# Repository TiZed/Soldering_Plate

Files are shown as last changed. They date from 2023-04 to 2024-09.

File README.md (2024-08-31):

## Soldering Plate Device

This repository holds the mechanical, circuit design and firmware for a soldering plate device, built around cheap heating plates that can be bought online.

The enclosure, pictured below, is designed to be 3D printed. Some of the STLs are available in the repository.

There are two circuits, one for supplying 5V from mains to the control circuits. The second is a control circuit, for mounting an encoder for user input. Control is done using a STM32F103 board known as the "Blue Pill". 

<h3 align="center">
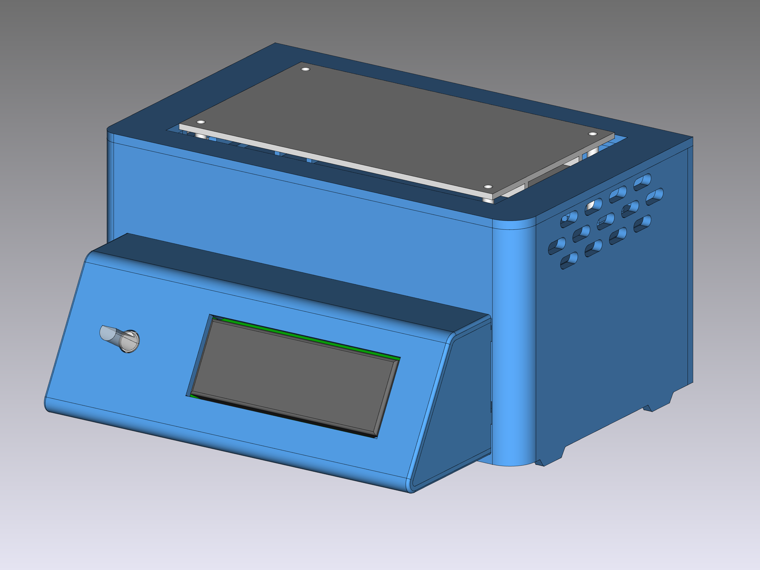
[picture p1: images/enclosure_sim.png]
Enclosure render
  
</h3>
Enclosure Render

---
<br />This work is licensed under a <a rel="license" href="http://creativecommons.org/licenses/by-nc-sa/4.0/">Creative Commons Attribution-NonCommercial-ShareAlike 4.0 International License</a>.

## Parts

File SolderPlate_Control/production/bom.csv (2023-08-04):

Designator | Footprint | Quantity | Value | LCSC Part #
C1, C2 | 0603 | 2 | 10nF
J1 | PinHeader_2x04_P2.54mm_Vertical | 1 | Encoder
Q1, Q4 | SOT-23 | 2 | Si2301CDS
R1, R4, R5, R6, R7 | 0603 | 5 | 10K
R10, R9 | 0603 | 2 | 470
R13, R14 | 0603 | 2 | 1K
R2 | 0603 | 1 | 120
R3 | 0603 | 1 | 68
U1 | RotaryEncoder_Bourns_Vertical_PEL12D-2xxxX-Sxxxx | 1 | PEL12D

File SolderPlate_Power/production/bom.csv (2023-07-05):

Designator | Footprint | Quantity | Value | LCSC Part #
C1 | C_Rect_L13.0mm_W6.0mm_P10.00mm_FKS3_FKP3_MKS4 | 1 | 100nF
C2 | CP_Elec_6.3x7.7 | 1 | 220uF
C3 | 0603 | 1 | 100nF
FL2 | L_CommonMode_PROD_PDUUAT98_L17mm_W12mm_Px7mm_Py8mm | 1 | 10mH
J1 | TestPoint_Bridge_Pitch5.08mm_Drill1.3mm | 1 | N
J2 | JST_XH_B2B-XH-A_1x02_P2.50mm_Vertical | 1 | Fan
J3 | TestPoint_Bridge_Pitch5.08mm_Drill1.3mm | 1 | L
J4 | JST_XH_B2B-XH-A_1x02_P2.50mm_Vertical | 1 | SSR
J5 | PinHeader_1x04_P2.54mm_Vertical | 1 | LCD
J7 | PinHeader_2x03_P2.54mm_Vertical | 1 | uCont
PS1 | Converter_ACDC_HiLink_HLK-PMxx | 1 | HLK-PM01
Q1, Q2, Q3 | SOT-23 | 3 | BSS138
R1 | 0603 | 1 | 68
R2, R4, R6 | 0603 | 3 | 470
R3, R5, R7 | 0603 | 3 | 10K
RV1 | RV_Disc_D12mm_W6.7mm_P7.5mm | 1 | 10D561K

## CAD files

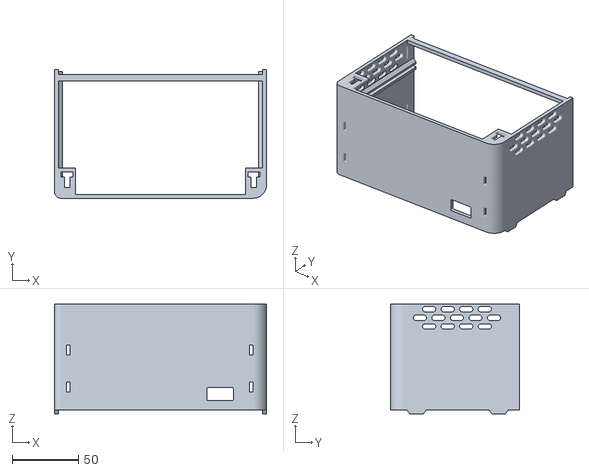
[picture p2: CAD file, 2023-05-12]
Soldering_Plate-MainCover.stl
160.0 x 97.0 x 83.0

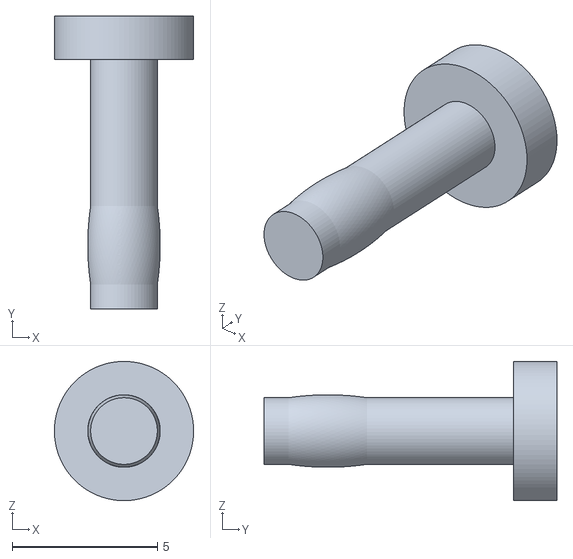
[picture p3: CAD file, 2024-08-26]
Soldering_Plate-LCD_Hold_Pin.stl
4.80 x 10.1 x 4.80

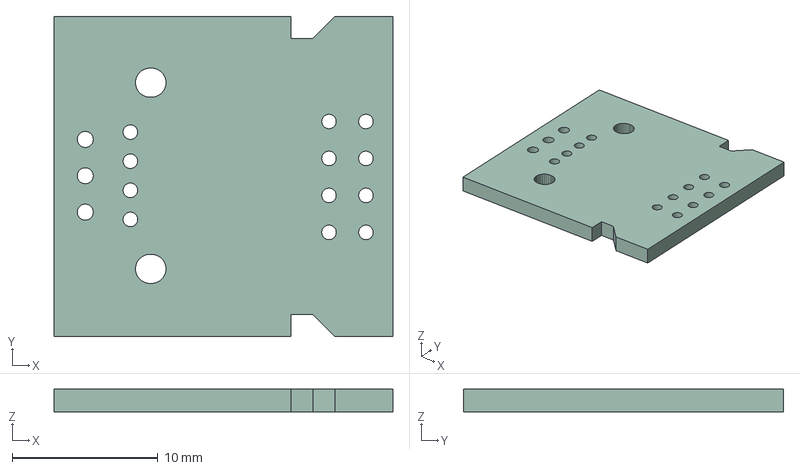
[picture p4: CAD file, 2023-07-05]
SolderPlate_Control/SolderPlate_Control.step
23.3 x 22.0 x 1.58 mm

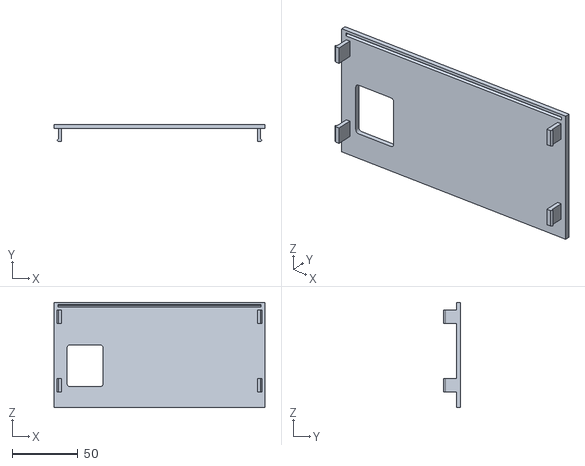
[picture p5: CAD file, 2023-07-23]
Soldering_Plate-BackCover.stl
160.0 x 12.8 x 80.0

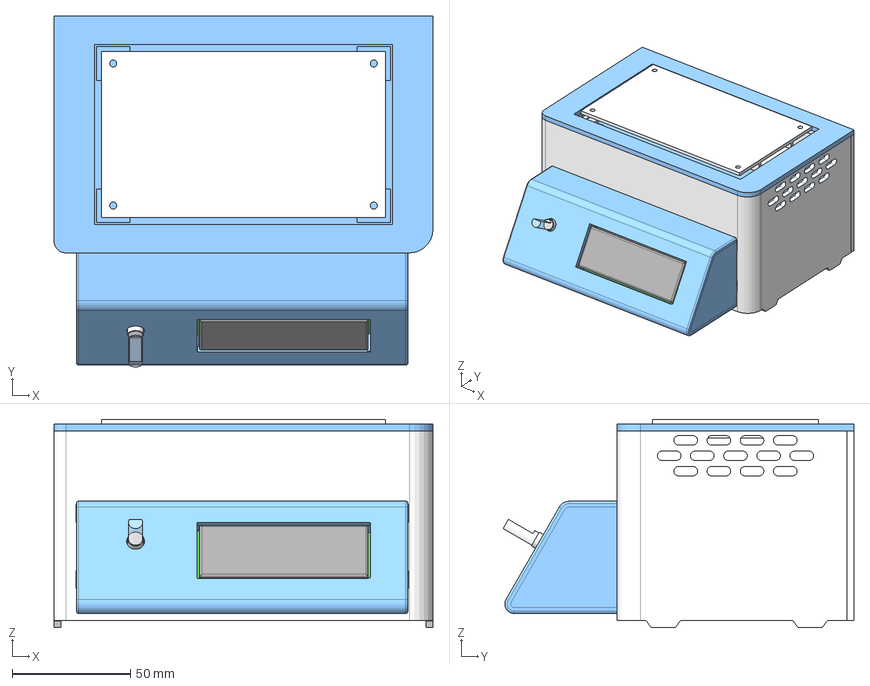
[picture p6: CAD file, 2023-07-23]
Soldering_Plate.FCStd
160.0 x 148.1 x 88.0 mm
LegBase
Work_top
Heat_Plate
BluePill
SSR
ShaftBase
Shaft
EncoderBody
MetalCover
Display
PCB
BackTabsLow
BackTabsHigh
MainCover
BottomBase
BackCover
Body (mirrored)
Pcb_b383

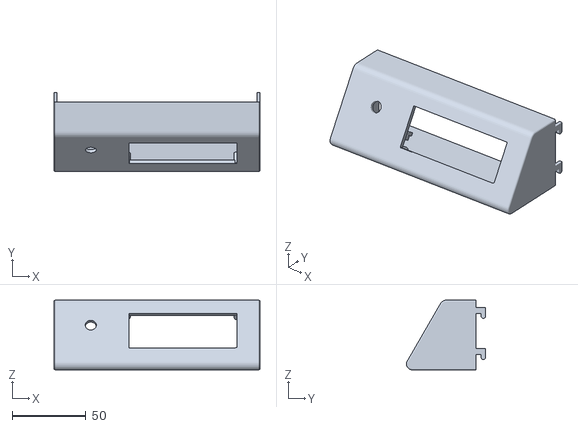
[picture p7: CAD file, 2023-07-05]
Soldering_Plate-FrontPanel.stl
140.0 x 53.8 x 47.5

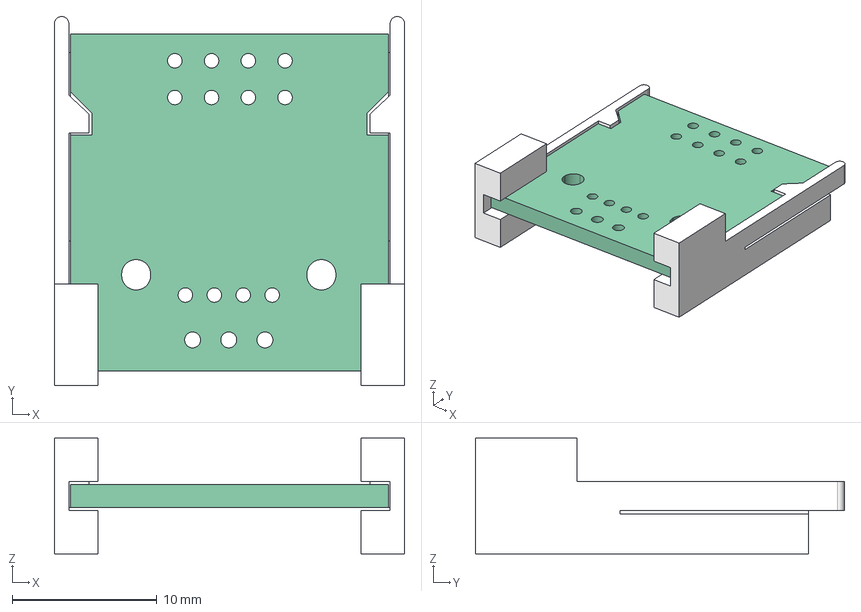
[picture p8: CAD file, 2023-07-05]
Control_Latch_Design.FCStd
24.2 x 25.5 x 8.00 mm
Pcb_b383
Body (mirrored)

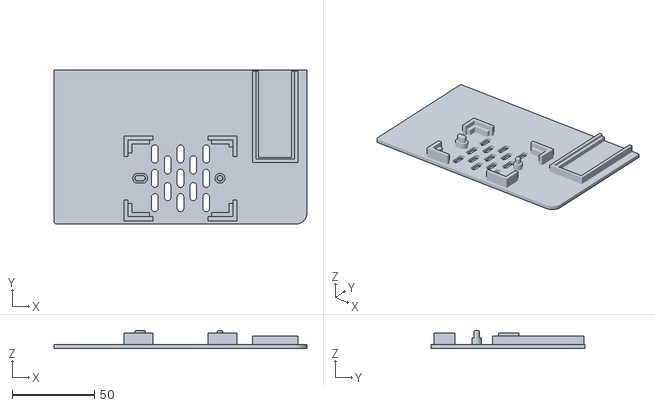
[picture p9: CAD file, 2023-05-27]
Soldering_Plate-BottomBase.stl
153.6 x 93.6 x 11.0

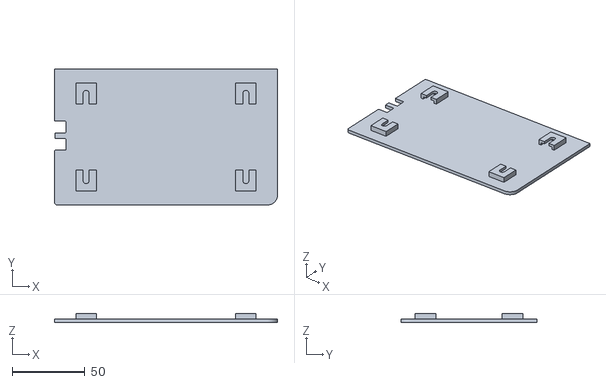
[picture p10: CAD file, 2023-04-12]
Soldering_Plate-LegBase.stl
153.6 x 93.6 x 6.50

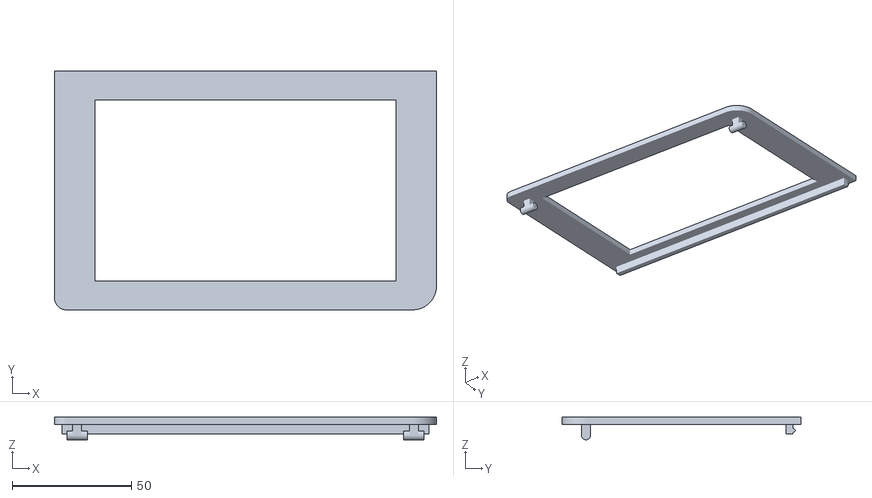
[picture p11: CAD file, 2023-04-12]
Soldering_Plate-Work_top.stl
160.0 x 100.0 x 9.50

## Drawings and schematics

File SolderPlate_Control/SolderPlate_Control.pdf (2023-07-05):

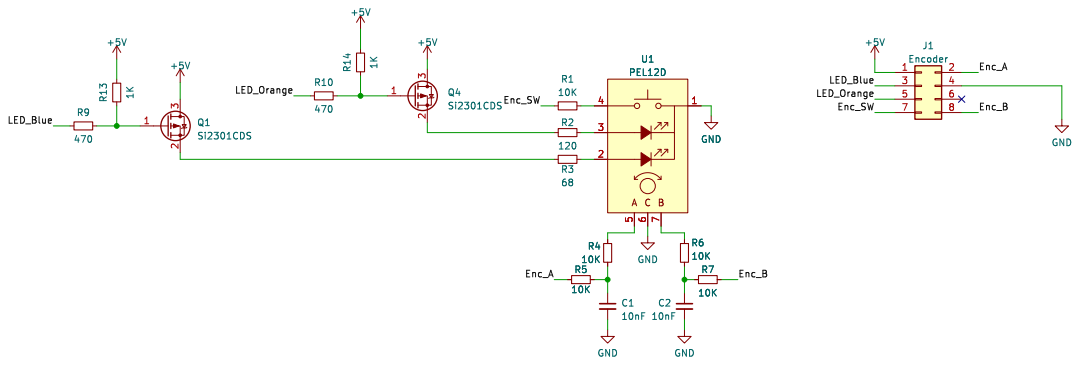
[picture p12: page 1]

Id: 1/1 Title: Solder Plate - Control Board

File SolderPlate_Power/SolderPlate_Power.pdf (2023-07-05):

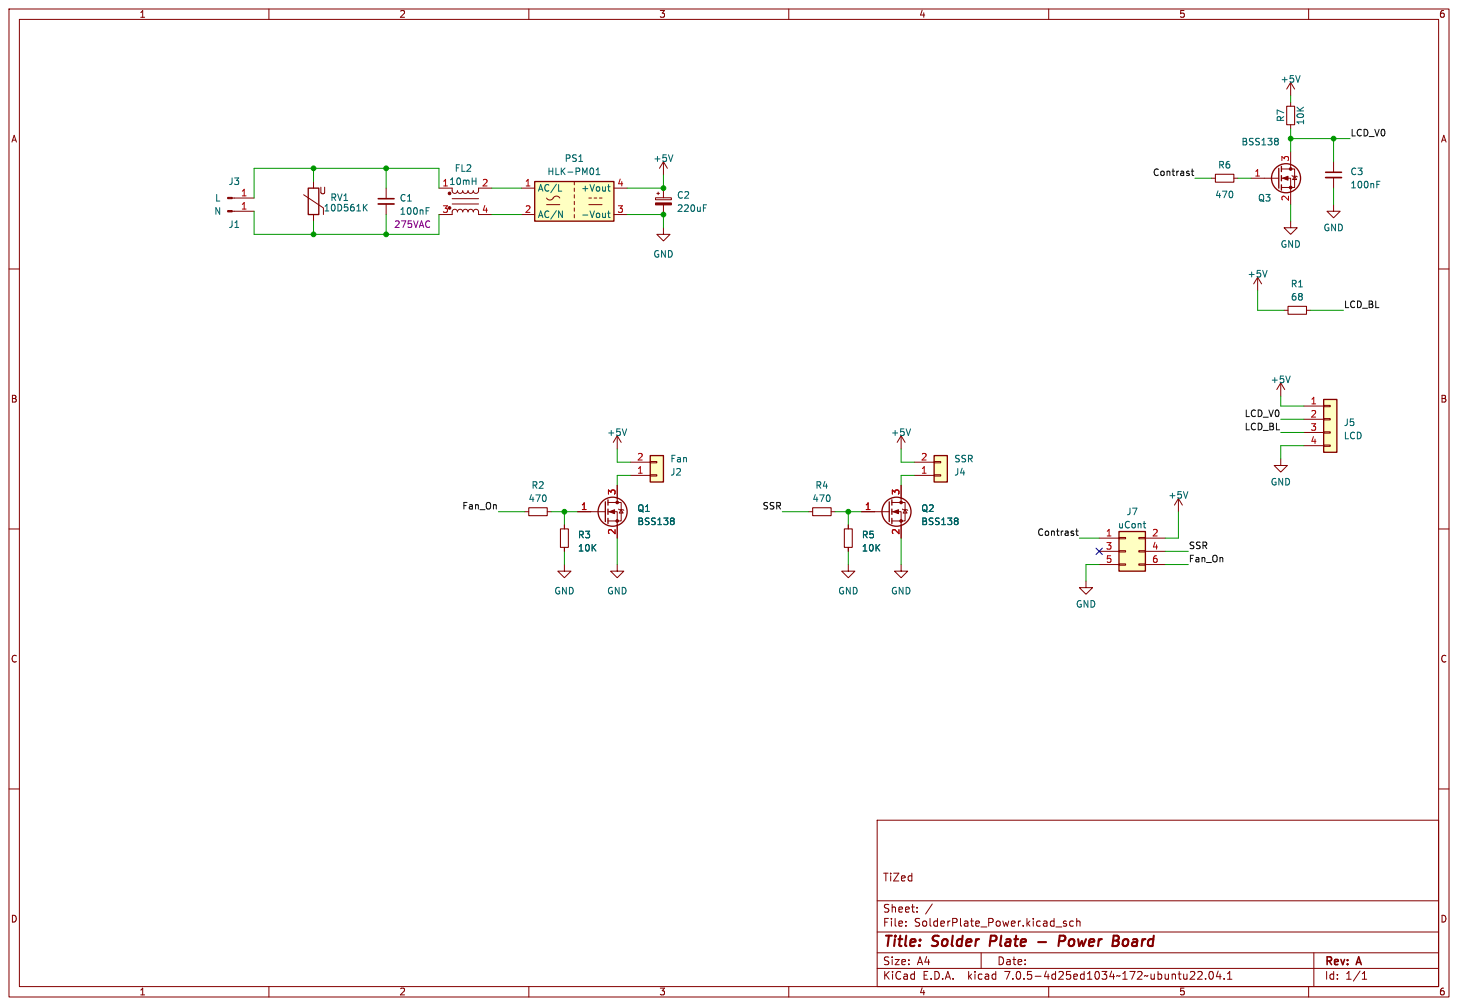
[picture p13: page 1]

Id: 1/1 Title: Solder Plate - Power Board

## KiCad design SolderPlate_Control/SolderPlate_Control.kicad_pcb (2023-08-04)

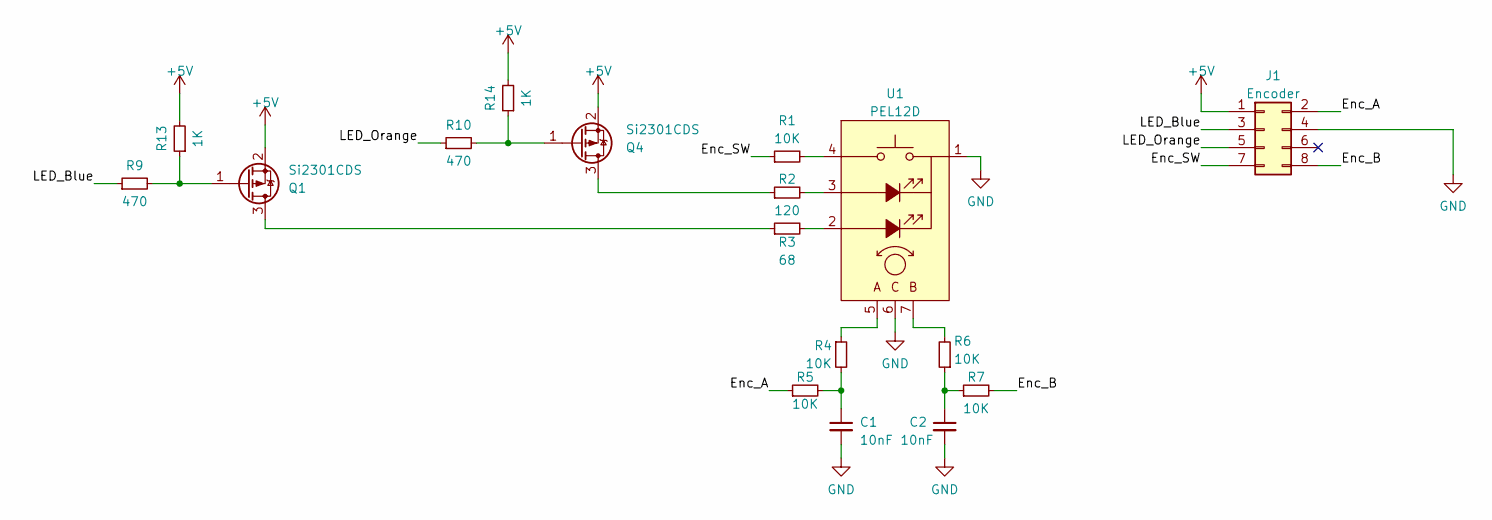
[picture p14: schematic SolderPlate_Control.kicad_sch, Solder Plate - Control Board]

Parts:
C1, C2: 10nF; C_0603_1608Metric
J1: Encoder; PinHeader_2x04_P2.54mm_Vertical
Q1, Q4: Si2301CDS; SOT-23
R1, R4, R5, R6, R7: 10K; R_0603_1608Metric
R2: 120; R_0603_1608Metric
R3: 68; R_0603_1608Metric
R9, R10: 470; R_0603_1608Metric
R13, R14: 1K; R_0603_1608Metric
U1: PEL12D; RotaryEncoder_Bourns_Vertical_PEL12D-2xxxX-Sxxxx

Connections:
+5V: J1.1, Q1.2 (S), Q4.2 (S), R13.2, R14.2
/Enc_A: J1.2, R5.1
/Enc_B: J1.8, R7.2
/Enc_SW: J1.7, R1.1
/LED_Blue: J1.3, R9.1
/LED_Orange: J1.5, R10.1
GND: C1.2, C2.2, J1.4, U1.1 (COM), U1.6 (C)
unnamed: C1.1, R4.2, R5.2
unnamed: C2.1, R6.1, R7.1
unnamed: Q1.3 (D), R3.1
unnamed: Q1.1 (G), R9.2, R13.1
unnamed: Q4.3 (D), R2.1
unnamed: Q4.1 (G), R10.2, R14.1
unnamed: R3.2, U1.2 (A1)
unnamed: R2.2, U1.3 (A2)
unnamed: R4.1, U1.5 (A)
unnamed: R6.2, U1.7 (B)
unnamed: R1.2, U1.4 (SW)

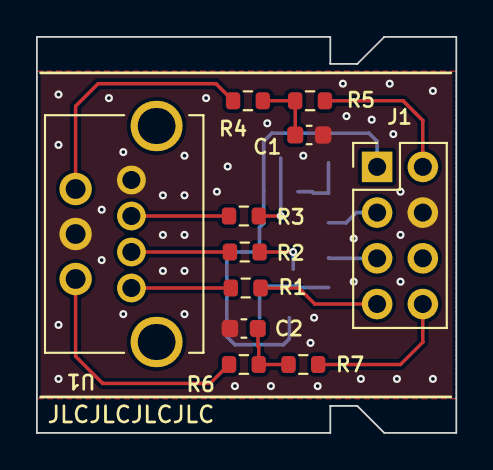
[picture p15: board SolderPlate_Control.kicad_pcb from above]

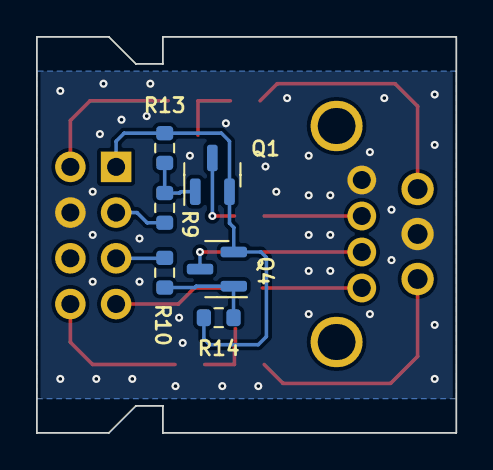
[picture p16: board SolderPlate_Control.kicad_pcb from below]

Board: 2 copper layers, 23.3 x 22.0 mm, 17 parts (6 on the bottom side), 18 nets.

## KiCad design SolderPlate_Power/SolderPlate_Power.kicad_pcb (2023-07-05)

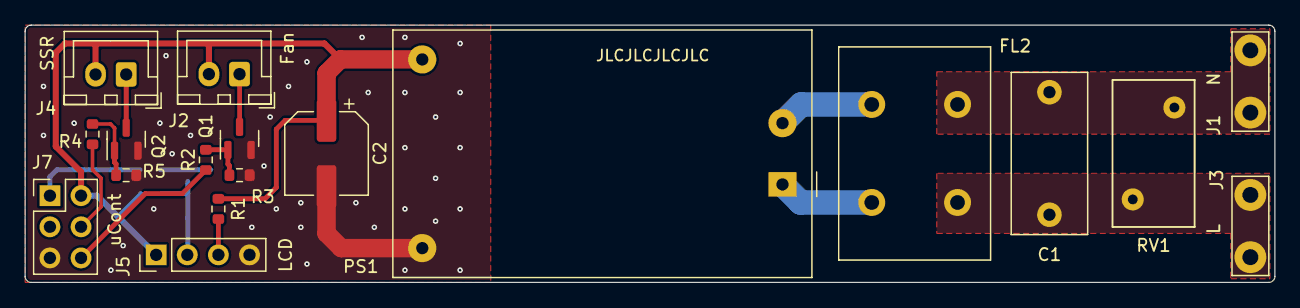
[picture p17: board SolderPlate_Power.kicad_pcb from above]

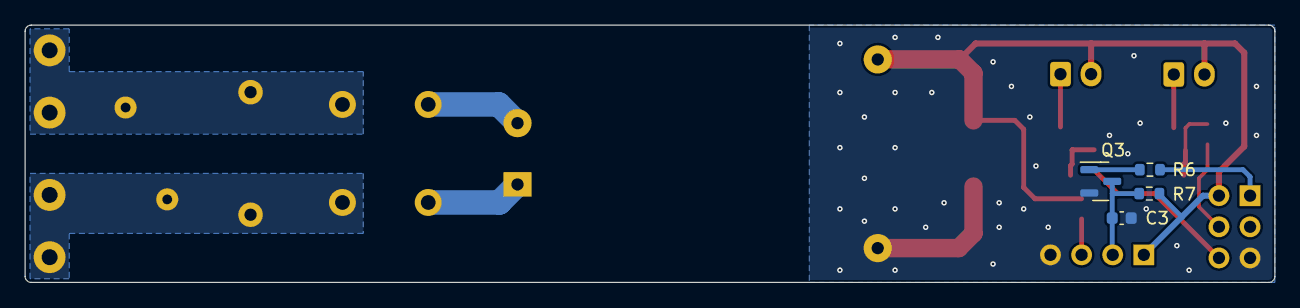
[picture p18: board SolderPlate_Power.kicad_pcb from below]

Board: 2 copper layers, 102.0 x 21.0 mm, 22 parts (4 on the bottom side), 16 nets.

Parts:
C1: 100nF; C_Rect_L13.0mm_W6.0mm_P10.00mm_FKS3_FKP3_MKS4
C2: 220uF; CP_Elec_6.3x7.7
C3: 100nF; C_0603_1608Metric
FL2: 10mH; L_CommonMode_PROD_PDUUAT98_L17mm_W12mm_Px7mm_Py8mm
J1: N; TestPoint_Bridge_Pitch5.08mm_Drill1.3mm
J2: Fan; JST_XH_B2B-XH-A_1x02_P2.50mm_Vertical
J3: L; TestPoint_Bridge_Pitch5.08mm_Drill1.3mm
J4: SSR; JST_XH_B2B-XH-A_1x02_P2.50mm_Vertical
J5: LCD; PinHeader_1x04_P2.54mm_Vertical
J7: uCont; PinHeader_2x03_P2.54mm_Vertical
PS1: HLK-PM01; Converter_ACDC_HiLink_HLK-PMxx
Q1, Q2, Q3: BSS138; SOT-23
R1: 68; R_0603_1608Metric
R2, R4, R6: 470; R_0603_1608Metric
R3, R5, R7: 10K; R_0603_1608Metric
RV1: 10D561K; RV_Disc_D12mm_W6.7mm_P7.5mm

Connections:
+5V: C2.1, J2.2, J4.2, J5.1, J7.2, PS1.4 (+Vout), R1.1, R7.2
/Contrast: J7.1, R6.1
/Fan_On: J7.6, R2.1
/LCD_BL: J5.3, R1.2
/LCD_V0: C3.1, J5.2, Q3.3 (D), R7.1
/SSR: J7.4, R4.1
GND: C2.2, C3.2, J5.4, J7.5, PS1.3 (-Vout), Q1.2 (S), Q2.2 (S), Q3.2 (S), R3.1, R5.1
unnamed: C1.2, FL2.3, J1.1, RV1.1
unnamed: J2.1, Q1.3 (D)
unnamed: C1.1, FL2.1, J3.1, RV1.2
unnamed: J4.1, Q2.3 (D)
unnamed: FL2.2, PS1.1 (AC/L)
unnamed: FL2.4, PS1.2 (AC/N)
unnamed: Q1.1 (G), R2.2, R3.2
unnamed: Q2.1 (G), R4.2, R5.2
unnamed: Q3.1 (G), R6.2

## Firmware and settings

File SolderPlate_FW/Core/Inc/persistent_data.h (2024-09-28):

#ifndef __PERSISTENT_DATA_H
#define __PERSISTENT_DATA_H

#ifdef __cplusplus
extern "C" {
#endif

#include <stdint.h>

#define DEFAULT_P_GAIN   15.0 
#define DEFAULT_D_GAIN    0.0 
#define DEFAULT_I_GAIN    0.0 
#define DEFAULT_I_MIN     0.0 
#define DEFAULT_I_MAX   200.0

#define HEADER_VAL  0xCAFEC0DE08691234UL

typedef struct {
    uint64_t header_dword ;
    double p_gain ;
    double i_gain ;
    double d_gain ;
    double i_min ;
    double i_max ;
} persistent_vars_t ;

typedef union {
    persistent_vars_t values ;
    uint32_t pers_bits[sizeof(persistent_vars_t)/sizeof(uint32_t)] ;
} persistent_store_t ;

extern persistent_store_t persistent_store ;
extern persistent_vars_t * persistent_data ;

uint32_t persistent_save() ;
uint32_t persistent_load() ;

#ifdef __cplusplus
}
#endif

#endif /* __PERSISTENT_DATA_H */

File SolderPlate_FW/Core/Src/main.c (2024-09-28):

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
/* Includes ------------------------------------------------------------------*/
#include "main.h"
#include "usb_device.h"

/* USER CODE BEGIN Includes */
#include "usbd_cdc_if.h"
#include "usb_redirect.h"

#include <stdio.h>
#include <math.h>
#include <stdint.h>
#include <stdbool.h>

#include "lcd16x2.h"
#include "config.h"
#include "thermistor.h"
#include "leds.h"
#include "pid.h"
#include "cli.h"
#include "state.h"
#include "persistent_data.h"
#include "menu.h"
/* USER CODE END Includes */

/* USER CODE BEGIN PD */
#define ADC_VDDA  (3.3)             // V
#define ADC_RANGE (4096)
#define THRM_AVG  (40)

#define LED_RANGE ((2 << 16) - 1)
#define LED_RATE  (100)

#define LCD_BLINK_RATE (30)        // x30mS

#define SHORT_PRESS (5)            // x10mS
#define LONG_PRESS  (100)          // x10mS

#define INT_TEMP_STEP   (4.3)       // mV
#define INT_TEMP_V25    (1430.0)    // mV

#define ADC_THRM_CH     (0)
#define ADC_INTTEMP_CH  (1)
#define ADC_VREF_CH     (2)

/* USER CODE END PD */

ADC_HandleTypeDef hadc1;
DMA_HandleTypeDef hdma_adc1;

IWDG_HandleTypeDef hiwdg;

TIM_HandleTypeDef htim1;
TIM_HandleTypeDef htim2;
TIM_HandleTypeDef htim3;

/* USER CODE BEGIN PV */

/*
Timer1 - Encoder input
Timer2 - PWM generator: 
         Ch1 - Orange Encoder LED
         Ch2 - Blue Encoder LED
         Ch3 - LCD contrast
Timer3 - 10msec clock

*/

/* USER CODE END PV */

void SystemClock_Config(void);
static void MX_GPIO_Init(void);
static void MX_DMA_Init(void);
static void MX_ADC1_Init(void);
static void MX_TIM1_Init(void);
static void MX_TIM2_Init(void);
static void MX_TIM3_Init(void);
static void MX_IWDG_Init(void);
/* USER CODE BEGIN PFP */

extern uint32_t _estack;

static inline void reset_to_bootloader() {
  uint64_t * ptr = (uint64_t*)&_estack;
	*ptr = 0xDEADBEEFCC00FFEEULL;

  NVIC_SystemReset() ;
}

/* USER CODE END PFP */

/* USER CODE BEGIN 0 */
volatile uint16_t adc_results[3] ;
uint16_t thrm_res_buffer[THRM_AVG] ;

static uint16_t thrm_buf_idx = 0 ;
static uint16_t ssr_on_counter = 0 ;
static float plate_set_temp = DEFAULT_TEMP ; 
static float user_set_temp = DEFAULT_TEMP ; 

uint8_t ssr_off_char[8] = {0x1f, 0x11, 0x11, 0x11, 0x11, 0x11, 0x1f, 0x00} ;
uint8_t ssr_on_char[8]  = {0x1f, 0x1f, 0x1f, 0x1f, 0x1f, 0x1f, 0x1f, 0x00} ;

leds_state_t * orange_led ;
leds_state_t * blue_led ;

volatile uint32_t sec_ticker = 0 ;
volatile struct enc_button_s enc_button = {BUTTON_DONE, 0} ;
volatile uint32_t lcd_timer = 2 * LCD_BLINK_RATE ;
bool is_lcd_blink = false ;

/* USER CODE END 0 */

/**
  * @brief  The application entry point.
  * @retval int
  */
int main(void)
{

  /* USER CODE BEGIN 1 */
  float plate_temp ;
  float therm_rt ;
  char temp_update[17] ;
  int32_t last_count ;

  SystemState = SYS_POWER_UP ;
  
  /* USER CODE END 1 */

  /* MCU Configuration--------------------------------------------------------*/

  /* Reset of all peripherals, Initializes the Flash interface and the Systick. */
  HAL_Init();

  /* Configure the system clock */
  SystemClock_Config();

  /* Initialize all configured peripherals */
  MX_GPIO_Init();
  MX_DMA_Init();
  MX_ADC1_Init();
  MX_TIM1_Init();
  MX_TIM2_Init();
  MX_USB_DEVICE_Init();
  MX_TIM3_Init();
  MX_IWDG_Init();
  /* USER CODE BEGIN 2 */

//  setvbuf(stdout, NULL, _IONBF, 0);
  HAL_ADCEx_Calibration_Start(&hadc1) ;

  HAL_GPIO_WritePin(BP_LED_GPIO_Port, BP_LED_Pin, GPIO_PIN_RESET) ;
  HAL_GPIO_WritePin(SSR_GPIO_Port, SSR_Pin, GPIO_PIN_RESET) ;
  HAL_GPIO_WritePin(Fan_GPIO_Port, Fan_Pin, GPIO_PIN_RESET) ;

  HAL_TIM_PWM_Start(&htim2, TIM_CHANNEL_1) ;
  HAL_TIM_PWM_Start(&htim2, TIM_CHANNEL_2) ;
  HAL_TIM_PWM_Start(&htim2, TIM_CHANNEL_3) ;

  init_leds(100) ;
  orange_led = new_led(16, &(TIM2->CCR1)) ;
  blue_led = new_led(16, &(TIM2->CCR2)) ;

  set_led(blue_led, 20, 500) ;
//  printf("Start!\r\n") ;
  HAL_IWDG_Refresh(&hiwdg) ;

  TIM2->CCR3 = 27000 ; // LCD contrast

  HAL_TIM_Encoder_Start(&htim1, TIM_CHANNEL_ALL) ;
  
  LCD_Init(DispD0_GPIO_Port, IF_8BIT, 
           DispRW_Pin, DispRS_Pin, DispE_Pin,
           DispD0_Pin, DispD1_Pin, DispD2_Pin, DispD3_Pin, 
           DispD4_Pin, DispD5_Pin, DispD6_Pin, DispD7_Pin) ;

  LCD_SetCustomChar(1, ssr_off_char) ;
  LCD_SetCustomChar(2, ssr_on_char) ;

  LCD_SetPosition(LINE_1, 0) ;
  LCD_Print("  Temp.   Set  \x01") ;
//           1234567890123456
  
//  setvbuf(stdout, NULL, _IONBF, 0);
  plate_temp = 0.0 ;
  therm_rt = 0.0 ;
  last_count = TIM1->CNT ;

  HAL_IWDG_Refresh(&hiwdg) ;
  if (persistent_load() != HAL_OK) {
    LCD_SetPosition(LINE_1, 0) ;
    LCD_Print("Config Error!") ;

    Error_Handler();
  }

  pid_config_t * plate_pid = init_pid(persistent_data->p_gain, 
                                      persistent_data->i_gain, 
                                      persistent_data->d_gain, 
                                      persistent_data->i_min,
                                      persistent_data->i_max) ;

  uint8_t update_display = 1 ; 

  HAL_TIM_Base_Start_IT(&htim3) ;

  // Reset to bootloader, if encoder button is pressed for more than 30sec.
  uint32_t press_start = 0 ;
  while(HAL_GPIO_ReadPin(EncButton_GPIO_Port, EncButton_Pin) == GPIO_PIN_RESET) {
    HAL_Delay(100) ;
    if(press_start++ > 50) reset_to_bootloader() ;
  }

  /* USER CODE END 2 */

  /* Infinite loop */
  /* USER CODE BEGIN WHILE */
  SystemState = SYS_RUNNING ;
  int32_t menu_i = 0 ;
  double current_value = 0.0 ;

  while (1)
  {
    // Accumulated enough thermal sensor captures to do an average  
    if(thrm_buf_idx >= THRM_AVG) {
      float thrm_sum = 0 ;

      // Average ADC readings
      for(int i = 0 ; i < THRM_AVG ; i++) thrm_sum += (float)thrm_res_buffer[i] ;
      thrm_sum /= THRM_AVG ;

      // Reset samples accumulator count
      thrm_buf_idx = 0 ;

      // Calculate plate temperature
      therm_rt = rt_by_ratio(thrm_sum / (float)ADC_RANGE, THERM_R1) ;
      plate_temp = calculate_temperature(therm_rt, THERM_BETA, THERM_R_T25) ;

      // Update PID and set plate SSR on time
      // On time is in 10mS resolution 
      double pid_res = update_pid(plate_pid, plate_set_temp - plate_temp, plate_temp) ;
      if(pid_res <= 0) ssr_on_counter = 0 ;
      else ssr_on_counter = (uint16_t)pid_res ; 

      update_display = 1 ;
    }

  // adc_v = ADC_VDDA * (thrm_sum / (float)ADC_RANGE) ;  
  
  //  adc_v = ADC_VDDA * ((float) adc_results[ADC_INTTEMP_CH] / (float) ADC_RANGE) ;
  //  int_temp = (INT_TEMP_V25 - adc_v * 1000) / INT_TEMP_STEP + 25 ;
  //  printf("IntTemp = %3.1f | VIntTemp = %1.3fV (%d)\n\r", int_temp, adc_v, adc_results[ADC_INTTEMP_CH]) ;

  //  adc_v = ADC_VDDA * ((float) adc_results[2] / (float) ADC_RANGE) ;
  //  printf("Vref = %1.3fV (%d)\n\r", adc_v, adc_results[2]) ;

    if(SystemState == SYS_RUNNING) {
      // Update set temperature value
      if((TIM1->CNT >> 2) - last_count) { 
        int32_t change = ((int32_t)(TIM1->CNT >> 2) - last_count) ;

        if (abs(change) < 10) user_set_temp += change * 1.0 ;
        else user_set_temp += change * 5.0 ;

        last_count = TIM1->CNT >> 2 ;

        if (user_set_temp > MAX_TEMP) user_set_temp = MAX_TEMP ;
        if (user_set_temp < MIN_TEMP) user_set_temp = MIN_TEMP ;

        if (user_set_temp != plate_set_temp) is_lcd_blink = true ;
        else is_lcd_blink = false ;

        update_display = 1 ; 
      }

      // Update LCD 
      if(update_display) {
        HAL_IWDG_Refresh(&hiwdg) ;

        LCD_SetPosition(LINE_1, 0) ;
        LCD_Print("  Temp.   Set  ") ;

        LCD_SetPosition(LINE_2, 0) ;

        if (is_lcd_blink && lcd_timer > LCD_BLINK_RATE) {
          snprintf(temp_update, 17, "% 3.1f\xb2\x43          ", plate_temp) ;
          LCD_Print(temp_update) ;
        }
        else {
          snprintf(temp_update, 17, "% 3.1f\xb2\x43  % 3.0f\xb2\x43 ", plate_temp, user_set_temp) ;
          LCD_Print(temp_update) ;
        }

        update_display = 0 ;
      }

      switch (enc_button.state)
      {
      case BUTTON_SHORT:
        plate_set_temp = user_set_temp ;
        is_lcd_blink = false ;
        enc_button.state = BUTTON_DONE ;
        break;
      case BUTTON_LONG:
        if (SystemState == SYS_RUNNING) SystemState = SYS_MENU ;
        enc_button.state = BUTTON_DONE ;
        break;
      case BUTTON_RELEASE:
        enc_button.state = BUTTON_DONE ;
        break;
      default:
        break;
      }
    }

    if(ssr_on_counter > 0) {
      LCD_SetPosition(LINE_1, 15) ;
      LCD_Print("\x02") ;
      HAL_GPIO_WritePin(SSR_GPIO_Port, SSR_Pin, GPIO_PIN_SET) ;
    }
    else {
      LCD_SetPosition(LINE_1, 15) ;
      LCD_Print("\x01") ;
      HAL_GPIO_WritePin(SSR_GPIO_Port, SSR_Pin, GPIO_PIN_RESET) ;
    }

    if (SystemState == SYS_MENU) {
      if((TIM1->CNT >> 2) - last_count) { 
        int32_t change = ((int32_t)(TIM1->CNT >> 2) - last_count) ;

        menu_i += change ;

        if (menu_i < 0) menu_i = 0 ;
        if (menu_i >= (int32_t) menu_size) menu_i = menu_size - 1 ;

        last_count = TIM1->CNT >> 2 ;

        current_value = *(user_menu[menu_i].value) ;

        update_display = 1 ;
      }

      if(update_display) {
        HAL_IWDG_Refresh(&hiwdg) ;
        LCD_SetPosition(LINE_1, 0) ;
        snprintf(temp_update, 17, "\xf6 %-13s", user_menu[menu_i].title) ;
        LCD_Print(temp_update) ;

        if (user_menu[menu_i].value != NULL) {
          LCD_SetPosition(LINE_2, 0) ;
          snprintf(temp_update, 17, " %-15.1f", current_value) ;
          LCD_Print(temp_update) ;
        }
        else {
          LCD_SetPosition(LINE_2, 0) ;
          snprintf(temp_update, 17, "               ") ;
          LCD_Print(temp_update) ;
        }

        update_display = 0 ;
      }

     
      switch (enc_button.state)
      {
      case BUTTON_SHORT:
        enc_button.state = BUTTON_DONE ;
        break;
      case BUTTON_LONG:
        SystemState = SYS_RUNNING ;
        enc_button.state = BUTTON_DONE ;
        break;
      case BUTTON_RELEASE:
        enc_button.state = BUTTON_DONE ;
        break;
      default:
        break;
      }
    }

    if (SystemState == SYS_RESET) HAL_NVIC_SystemReset() ;
    if (SystemState == SYS_BOOTLOADER_RESET) reset_to_bootloader() ;

    if (SystemState == SYS_CMD_EXEC) cli_exec() ;
 
    /* USER CODE END WHILE */

    /* USER CODE BEGIN 3 */
  }
  /* USER CODE END 3 */
}

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
/* USER CODE BEGIN 4 */
void HAL_GPIO_EXTI_Callback(uint16_t GPIO_Pin) {
  if (GPIO_Pin == EncButton_Pin) {
    if(HAL_GPIO_ReadPin(EncButton_GPIO_Port, EncButton_Pin) == GPIO_PIN_RESET) {
      enc_button.state = BUTTON_PRESS ;
      enc_button.timer = 0 ;
    }
    
    else if(HAL_GPIO_ReadPin(EncButton_GPIO_Port, EncButton_Pin) == GPIO_PIN_SET && enc_button.state == BUTTON_PRESS) {
      if (enc_button.timer > LONG_PRESS) enc_button.state = BUTTON_LONG ;
      else if(enc_button.timer > SHORT_PRESS) enc_button.state = BUTTON_SHORT ;
      else enc_button.state = BUTTON_RELEASE ;
    }
  }
}

void HAL_TIM_PeriodElapsedCallback(TIM_HandleTypeDef *htim) {
  static uint16_t led_counter = 0 ;

  if(htim == &htim3) {
    // Toggle onboard LED
    if(++led_counter == 100) {
      HAL_GPIO_TogglePin(BP_LED_GPIO_Port, BP_LED_Pin) ;
      sec_ticker++ ;
      led_counter = 0 ;
    }

    // Do ADC capture
    if((HAL_ADC_GetState(&hadc1) & HAL_ADC_STATE_REG_BUSY) == 0)
      HAL_ADC_Start_DMA(&hadc1, (uint32_t *) adc_results, 3) ;

    // Updates plate SSR on counter
    if(ssr_on_counter > 0) ssr_on_counter-- ;

    if(enc_button.state == BUTTON_PRESS) enc_button.timer++ ;

    if (lcd_timer == 0) lcd_timer = 2 * LCD_BLINK_RATE ;
    else lcd_timer-- ;

    // Update LEDs state
    update_leds() ;
  }
}

void HAL_ADC_ConvCpltCallback(ADC_HandleTypeDef* hadc){
  if(hadc == &hadc1) {
    if(thrm_buf_idx < THRM_AVG)
      thrm_res_buffer[thrm_buf_idx++] = adc_results[ADC_THRM_CH] ;
  }
}

void USB_CDC_RxHandler(uint8_t* Buf, uint32_t Len)
{
    char cmd_str[CMD_SIZE] ;

    memcpy(cmd_str, Buf, Len) ;
    cmd_str[Len] = '\0' ;

    cli_input(cmd_str) ;
}
/* USER CODE END 4 */
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


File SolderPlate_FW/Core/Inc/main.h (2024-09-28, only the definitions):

#define BP_LED_Pin GPIO_PIN_13
#define BP_LED_GPIO_Port GPIOC
#define Thermistor_Pin GPIO_PIN_0
#define Thermistor_GPIO_Port GPIOA
#define Contrast_Pin GPIO_PIN_2
#define Contrast_GPIO_Port GPIOA
#define SSR_Pin GPIO_PIN_3
#define SSR_GPIO_Port GPIOA
#define Fan_Pin GPIO_PIN_4
#define Fan_GPIO_Port GPIOA
#define DispD6_Pin GPIO_PIN_10
#define DispD6_GPIO_Port GPIOB
#define DispD7_Pin GPIO_PIN_11
#define DispD7_GPIO_Port GPIOB
#define DispE_Pin GPIO_PIN_12
#define DispE_GPIO_Port GPIOB
#define DispRW_Pin GPIO_PIN_13
#define DispRW_GPIO_Port GPIOB
#define DispRS_Pin GPIO_PIN_14
#define DispRS_GPIO_Port GPIOB
#define EncA_Pin GPIO_PIN_8
#define EncA_GPIO_Port GPIOA
#define EncB_Pin GPIO_PIN_9
#define EncB_GPIO_Port GPIOA
#define EncButton_Pin GPIO_PIN_10
#define EncButton_GPIO_Port GPIOA
#define EncButton_EXTI_IRQn EXTI15_10_IRQn
#define EncLedOrange_Pin GPIO_PIN_15
#define EncLedOrange_GPIO_Port GPIOA
#define EncLedBlue_Pin GPIO_PIN_3
#define EncLedBlue_GPIO_Port GPIOB
#define DispD0_Pin GPIO_PIN_4
#define DispD0_GPIO_Port GPIOB
#define DispD1_Pin GPIO_PIN_5
#define DispD1_GPIO_Port GPIOB
#define DispD2_Pin GPIO_PIN_6
#define DispD2_GPIO_Port GPIOB
#define DispD3_Pin GPIO_PIN_7
#define DispD3_GPIO_Port GPIOB
#define DispD4_Pin GPIO_PIN_8
#define DispD4_GPIO_Port GPIOB
#define DispD5_Pin GPIO_PIN_9
#define DispD5_GPIO_Port GPIOB
#define Disp_Port  GPIOB

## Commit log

2023-04-12 Initial commit of CAD and PCBs
    [SolderPlate_Control.kicad_pcb, SolderPlate_Control.kicad_sch, SolderPlate_Power.kicad_pcb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]
2023-04-21 Reduced Encoder control circuit to fit
    [SolderPlate_Control.kicad_pcb, SolderPlate_Control.kicad_sch]
2023-04-21 Rounded power board edges
    [SolderPlate_Power.kicad_pcb]
2023-04-21 Added circuits boards to mechnical design and fixed some positions
    [Soldering_Plate.FCStd]
2023-05-12 Fixes to main cover to shorten print time
    [Soldering_Plate-MainCover.stl, Soldering_Plate.FCStd]
2023-05-13 Shortend power supply board
    [SolderPlate_Power.kicad_pcb]
2023-05-13 Added bottom base STL
    [Soldering_Plate-BottomBase.stl]
2023-05-13 Updated power supply PCB mechanical model
2023-05-13 Fixed SSR size and base plate position
    [Soldering_Plate-BottomBase.stl, Soldering_Plate.FCStd]
2023-05-27 Export of new Bottom Base STL
    [Soldering_Plate-BottomBase.stl]
2023-07-05 Final PCBs and production files. Added latch for control wheel circuit
    [Control_Latch_Design.FCStd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]
2023-07-05 Added schematic PDFs
    [SolderPlate_Control.kicad_sch, SolderPlate_Power.kicad_sch]
2023-07-05 FW initial commit of STM32CubeMX project
2023-07-10 Changed STM32Cube project to makefile
2023-07-23 Added back cover STL
    [Soldering_Plate-BackCover.stl, Soldering_Plate.FCStd]
2023-07-23 Updated STM32CubeMX version. Using "STM32 for VSCode" for compile.
2023-07-27 Started actual FW coding. Added printf redirect to virtual COM port.
2023-07-30 ADC calibration and DMA reading
2023-08-03 Some pinout fixes and ADC fixes
    [SolderPlate_FW.ioc, main.c, main.h]
2023-08-04 Fixed wrongly routed P-MOSs in encoder control PCB
    [SolderPlate_Control-B_Cu.gbr, SolderPlate_Control-B_Mask.gbr, SolderPlate_Control-B_Paste.gbr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]
2023-08-04 Encoder control PCB updated production files
    [SolderPlate_Control-B_Cu.gbr, SolderPlate_Control-B_Mask.gbr, SolderPlate_Control-B_Paste.gbr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]
2023-08-04 Enabled encoder button: Button Interrupt LEDs PWM Encoder reading
2023-08-28 More display code. SW contrast adjust by V0 PWM.
2023-08-28 LCD printing working now. Fixed PB3 and PB4 designation so they work as GPIOs.
    [SolderPlate_FW.ioc, lcd16x2.c, main.c]
2023-08-29 Display temperatures
2023-09-01 Some temperature set logic
2023-09-01 Thermistor calculations code
2023-09-03 Improved display prints
2023-09-15 Added RT cyclic event 100 times a sec. Now averaging plate temperature. Added STM32 internal temperature calculation.
2023-09-17 Added LEDs control code
2023-09-22 Added PID control for hot plate
2024-08-26 Updated KiCad version for PCBs
    [SolderPlate_Power.kicad_sch]
2024-08-26 STL for LCD holding pins
    [Soldering_Plate-LCD_Hold_Pin.stl]
2024-08-26 Added custom LCD characters to indicate plate operation
2024-08-27 Updated STM32Cube FW to v1.8.6
2024-09-14 Fixed IWDG resets. Continue CLI coding
    [SolderPlate_FW.ioc, main.c]
2024-09-22 Got CLI working. Fixed some interrupt priorities. Started adding persistent data
    [SolderPlate_FW.ioc, main.c, persistent_data.c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]
2024-09-27 Added persistent PID parameters storage

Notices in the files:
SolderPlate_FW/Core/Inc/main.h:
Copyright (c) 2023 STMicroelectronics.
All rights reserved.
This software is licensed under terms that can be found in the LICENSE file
